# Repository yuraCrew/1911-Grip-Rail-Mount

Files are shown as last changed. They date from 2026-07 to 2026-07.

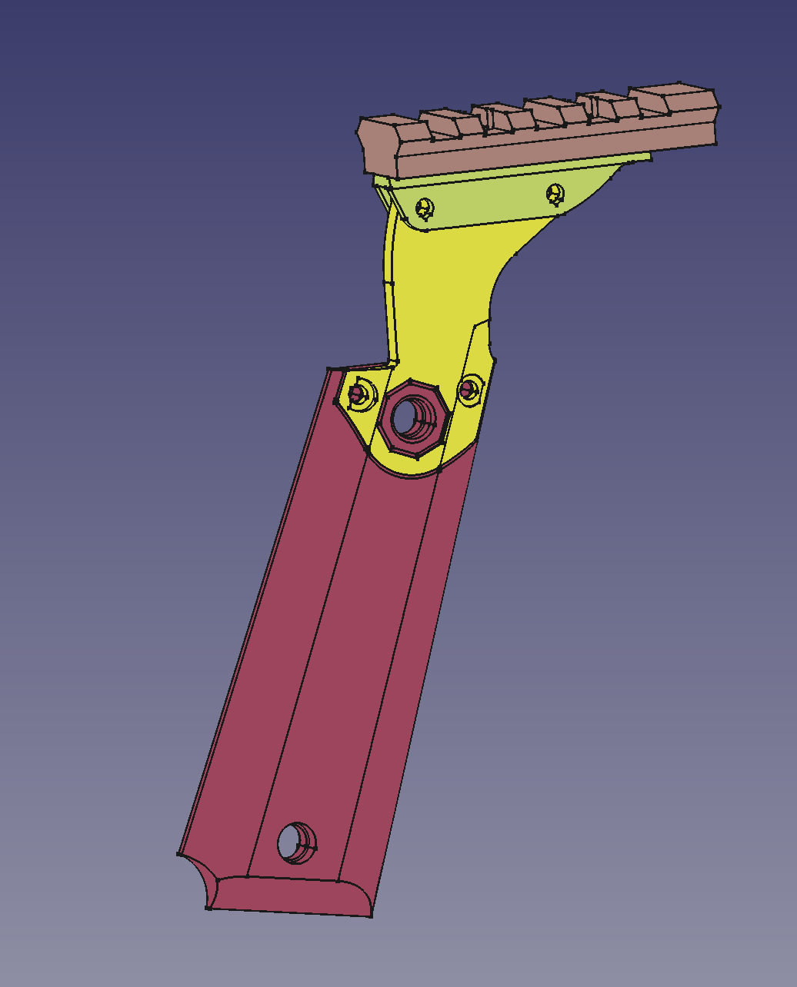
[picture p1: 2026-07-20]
images/render.png

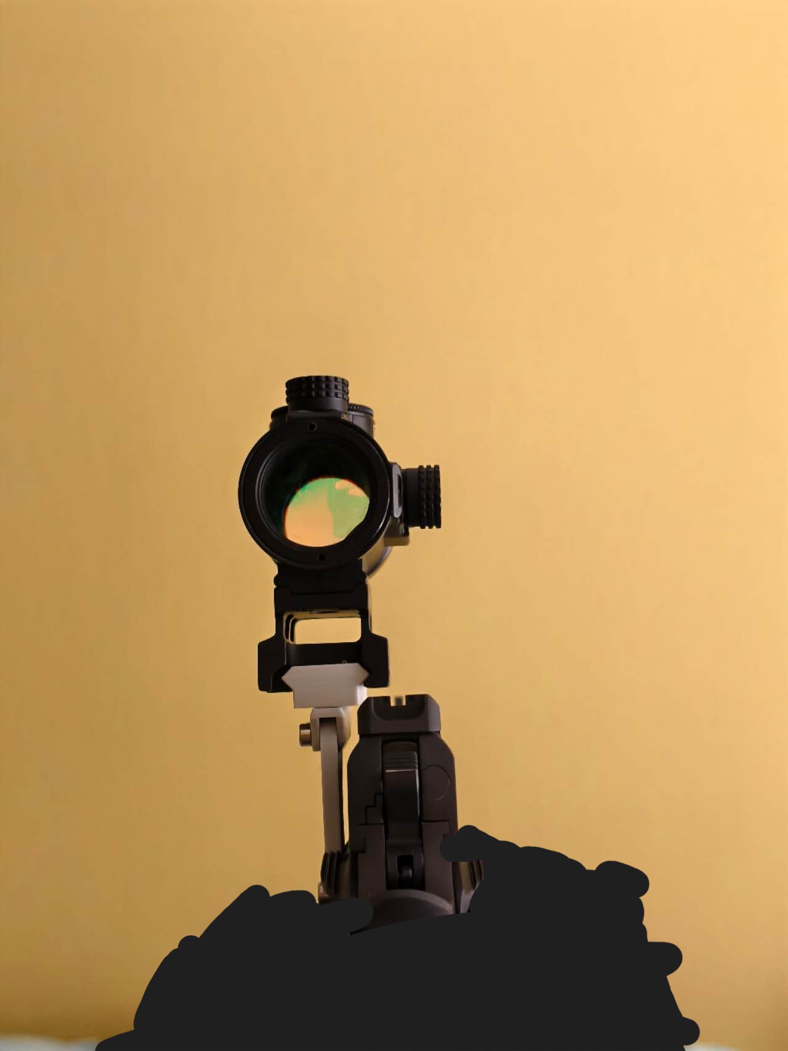
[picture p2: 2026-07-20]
images/biwitnessSights.jpg

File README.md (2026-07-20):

Replacement grip designed to add a frame mounted picatinny / dovetail rail to a 1911. The left grip is interchanged with a 3d printed counterpart which has an adapting socket to add a top rail. 

This design was a fun project that I slowly became serious about. After a few iterations I've got a general structure which should be the most efficient. Instead of mounting the scope above the center of the slide (being in line with the barrel), it is instead mounted directly above the grip. This reduces bending of the mount (as force is directly applied to the mount without any torque) and allows you to (bi witness?) with the original iron sights. The mount is also rested as low as possible (without obstructing the irons) to prevent bending when rapidly swinging the gun.

When you look at the gripMountOffset, you'll notice how it's canted oddly forward. The reason is because of the interaction between the rails and the iron sights. If extended another inch backwards, any scope rings in that area will hit the irons when the slide is racked. This would easily be solved by raising the height of the grip mount, but at that point you're sacrificing stability of the mount for a minor inconvenience; you're already holding the gun at arms length so what does a couple of inches do for you?

At the bottom right of the gripMountOffset, it looks like somebody took a rectangular cut out of the mount that would've provided a lot of stability. This cutout is room for 1911's with extended safeties such as the Rock Island Standard that I've been using. There is also the added benefit of allowing (some) room for your fingers to rack the slide. The left grooves on the slide are entirely shrouded and you only have the last bit of slide to grab onto. I've founded that the gun is impossible to rack without the hammer cocked so I'd recommend wearing grippy gloves.

Random Info:
I don't use any nuts because it complicates the design, all screws are threaded directly into the polymer because it works and it's easy. Apparantly there are "self tapping" m3 screws that exist but a regular m3 screw will work just fine and is what I use. It can be a bit tricky to get the screw started so what you can put an m3x20 in the chuck of a drill and start the thread that way.

The tolerance between the gripMountOffset and mainGrip is a press fit. I use a pair of vice grips to press them together but you can also use a hammer.

External Fasteners Required:

    2 M3x6 - Attach gripMountOffset to the mainGrip
    2 M3x8 - Attach railMount to gripMountOffset
    2 M3x6 - Attach either rail to railMount

Details for printing:

    The grip was designed on a technical drawing of the RIGHT grip. If printed as is, the ejection port will be entirely blocked and your gun won't function. Therefore, you must mirror all the components (technically the picatinny and dovetail rails won't change) before printing; this is easily done in all slicers.

    I've designed the components with zero supports intented, turn off all supports and print in the common sense orientation. 
    *The main grip does NOT need supports around the bushing area.

    All parts have been tested on a Qidi X-Smart 3 and function without post processing. Tolerances have been accounted for but I've provided the step files incase you need to alter them.

    I used PLA+ for all components but I reckon anything besides tpu will work great. Theoretically, the stiffer the material the better.

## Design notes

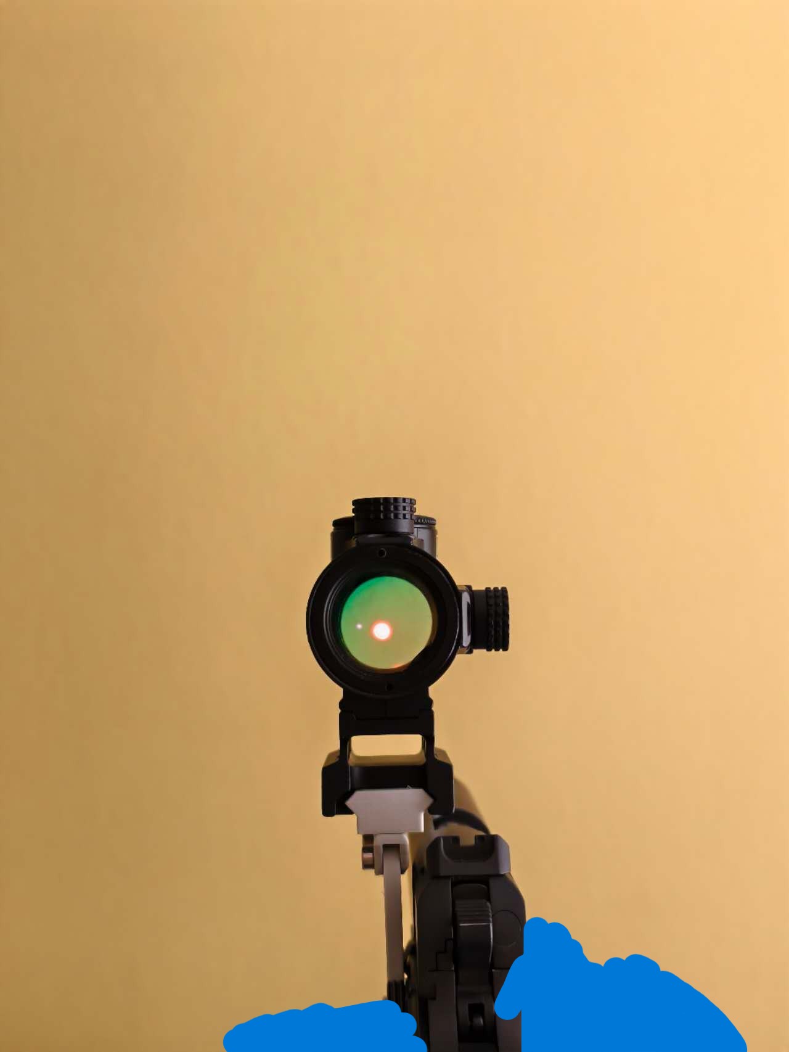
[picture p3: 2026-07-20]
images/redDotView.jpg

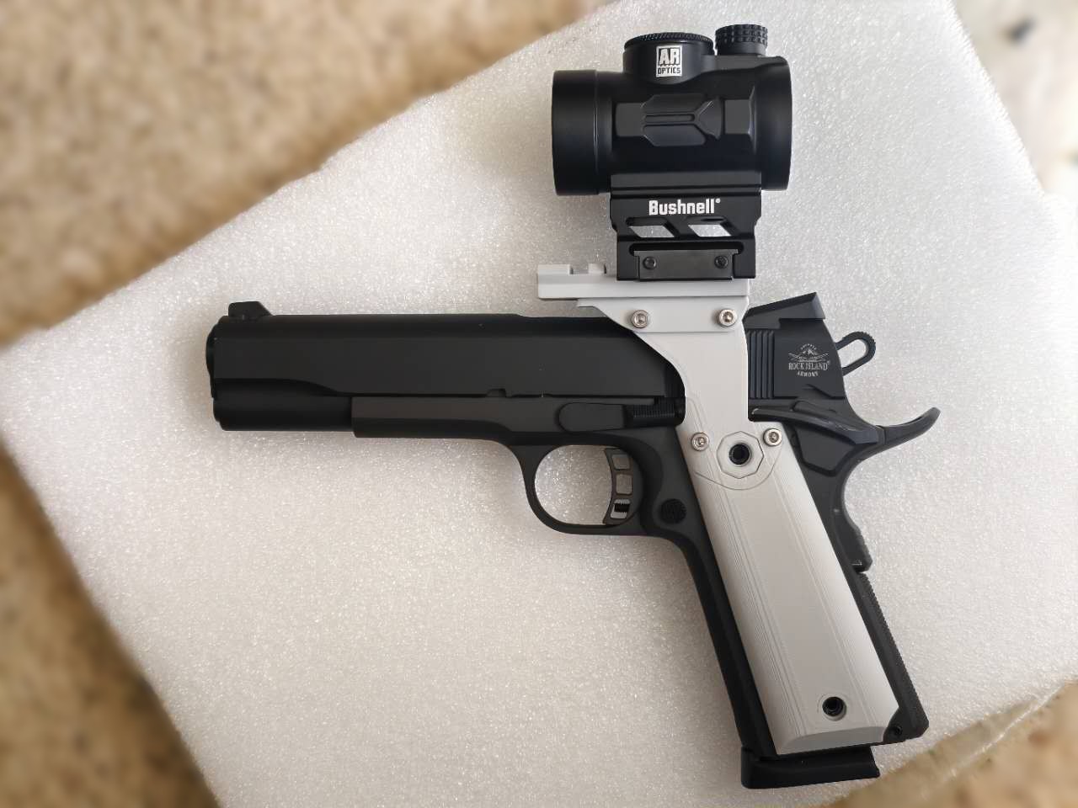
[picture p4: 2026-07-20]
images/generalProfile.jpg

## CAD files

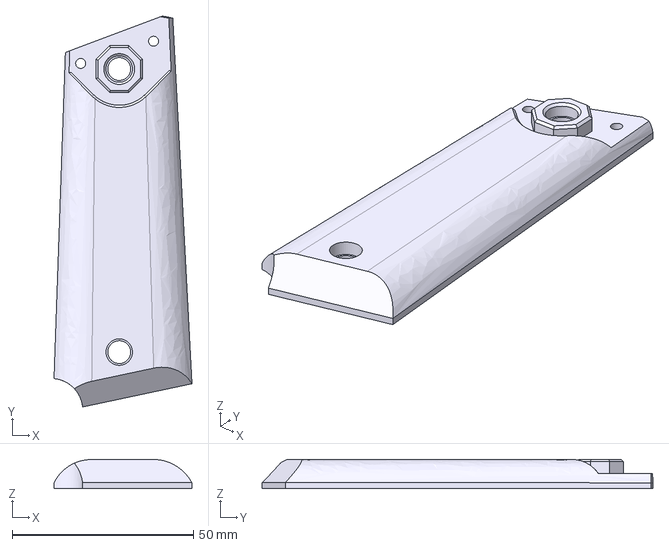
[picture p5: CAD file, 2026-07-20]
.step/mainGrip.step
38.1 x 107.8 x 8.00 mm

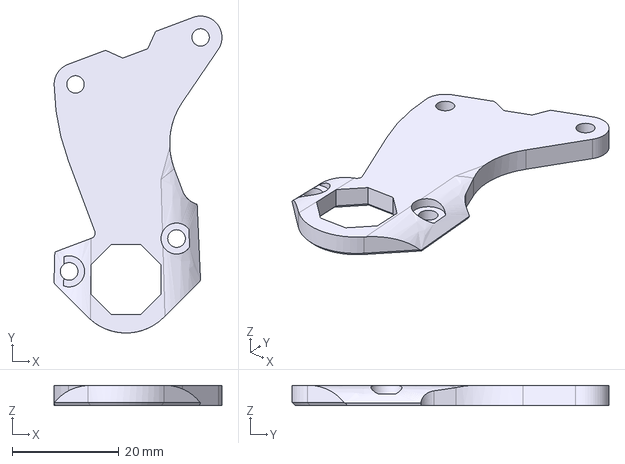
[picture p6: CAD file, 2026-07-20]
.step/gripMountOffset.step
31.4 x 59.3 x 3.80 mm

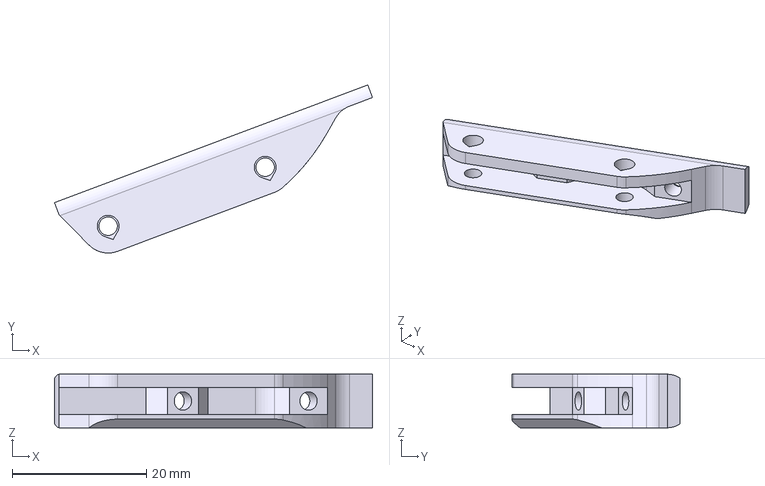
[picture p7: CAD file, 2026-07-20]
.step/railMount.step
47.4 x 25.0 x 8.00 mm

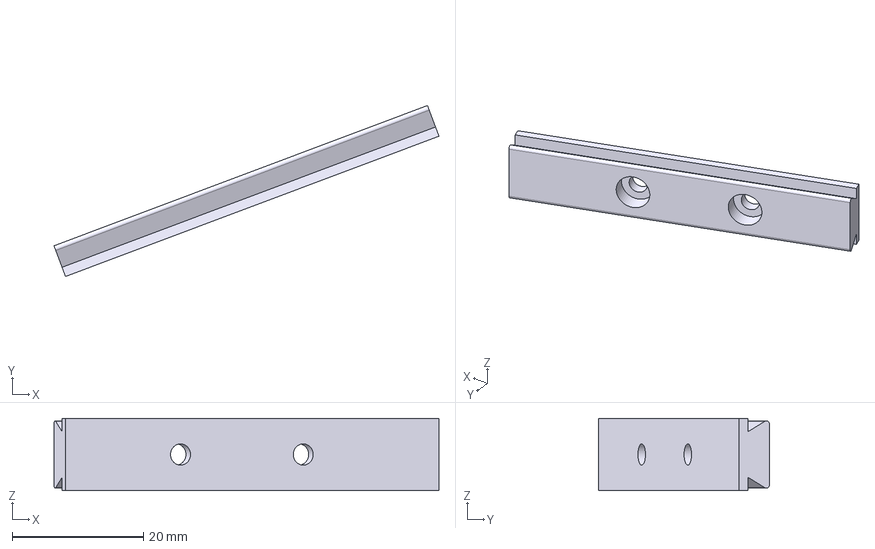
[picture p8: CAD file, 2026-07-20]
.step/dovetailMount.step
58.7 x 26.1 x 11.0 mm

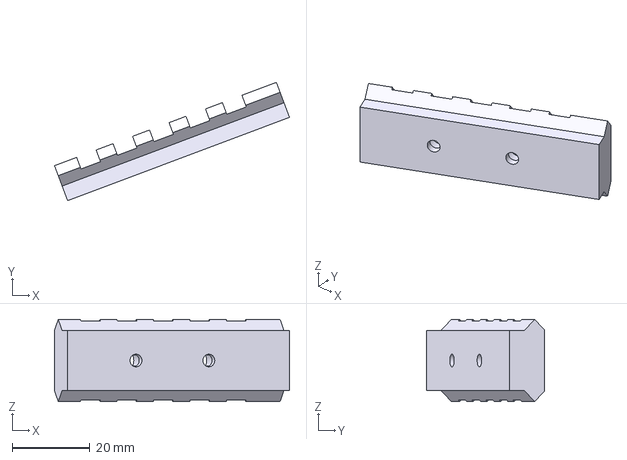
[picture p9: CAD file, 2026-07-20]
.step/picatinnyMount.step
60.4 x 30.4 x 21.1 mm

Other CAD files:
.stl/gripMount.stl
.stl/dovetailMount.stl
.stl/gripMountOffset.stl
.stl/picatinnyMount.stl
.stl/railMount.stl

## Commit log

2026-07-14 changed folder name
    [gripMount - Low.step, mainGrip.step]
2026-07-20 discard all previous files
    [gripMount - Low.step, mainGrip.step, ringMount - Low.step]
2026-07-20 uploaded all stl and step files
    [dovetailMount.step, dovetailMount.stl, gripMount.stl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]
2026-07-20 gripMountOffset Updates to step stl
    [gripMountOffset.step, gripMountOffset.stl]
